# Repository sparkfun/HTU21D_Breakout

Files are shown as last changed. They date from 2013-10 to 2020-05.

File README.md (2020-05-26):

**NOTE:** *This product has been retired from our catalog. If you are looking for more up-to-date info, please check out some of these resources to see how other users are still hacking and improving on this product.*
* *[SparkFun Forum](https://forum.sparkfun.com/)*
* *[Comments Here on GitHub](https://github.com/sparkfun/HTU21D_Breakout/issues)*

*We recommend looking at the [Si7021](https://www.sparkfun.com/products/13763), which is a drop-in replacement for the HTU21D. It uses the same address and methods to read the sensor.*

SparkFun Humidity and Temperature Sensor Breakout - HTU21D
===========================================================

SparkFun Humidity and Temperature Sensor Breakout - HTU21D  

[*SparkFun Humidity and Temperature Sensor Breakout - HTU21D (SEN-12064)*](https://www.sparkfun.com/products/12064)

This is a breadboard friendly breakout board for the Measurement Specialties high-precision, low-power digital humidity sensor.

Repository Contents
-------------------
* **/Firmware** - Example code 
* **/Hardware** - Eagle design files (.brd, .sch)
* **/Libraries** - Libraries for use with the <PRODUCT NAME>
* **/Production** - Production panel files (.brd)

Documentation
--------------
* **[Library](https://github.com/sparkfun/SparkFun_HTU21D_Breakout_Arduino_Library)** - Arduino library for the HTU21D.
* **[Hookup Guide](https://learn.sparkfun.com/tutorials/htu21d-humidity-sensor-hookup-guide)** - Basic hookup guide for the HTU21D.
* **[SparkFun Fritzing repo](https://github.com/sparkfun/Fritzing_Parts)** - Fritzing diagrams for SparkFun products.
* **[SparkFun 3D Model repo](https://github.com/sparkfun/3D_Models)** - 3D models of SparkFun products. 

License Information
-------------------
This product is _**open source**_! 

The **hardware** is released under [Creative Commons ShareAlike 4.0 International](https://creativecommons.org/licenses/by-sa/4.0/).

The **code** is beerware; if you see me (or any other SparkFun employee) at the local, and you've found our code helpful, please buy us a round!

Please use, reuse, and modify these files as you see fit. Please maintain attribution to SparkFun Electronics and release anything derivative under the same license.

Distributed as-is; no warranty is given.

- Your friends at SparkFun.

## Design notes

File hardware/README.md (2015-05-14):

SparkFun <PRODUCT NAME> Design Files
=====================================

The .sch and .brd files hare are Eagle CAD schematic and PCB design files from SparkFun Electronics.
A freeware version of Eagle can be found [here](http://www.cadsoftusa.com/download-eagle/freeware/). 

License
---------
This product is open source! 
The hardware is released under [Creative Commons ShareAlike 4.0 International](https://creativecommons.org/licenses/by-sa/4.0/).

Please use, reuse, and modify these files as you see fit. Please maintain attribution to SparkFun Electronics and release anything derivative under the same license.

Distributed as-is; no warranty is given.

- Your friends at SparkFun.

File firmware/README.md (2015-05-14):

SparkFun HTU21D Firmware
===================================

* **HTU21D_SimpleSketch** - Arduino simple sketch example. See video [here](https://youtu.be/HfNsybUKU6U). 
* **SparkFun_HTU21D_Example** - Arduino example sketch for getting started. No library required.

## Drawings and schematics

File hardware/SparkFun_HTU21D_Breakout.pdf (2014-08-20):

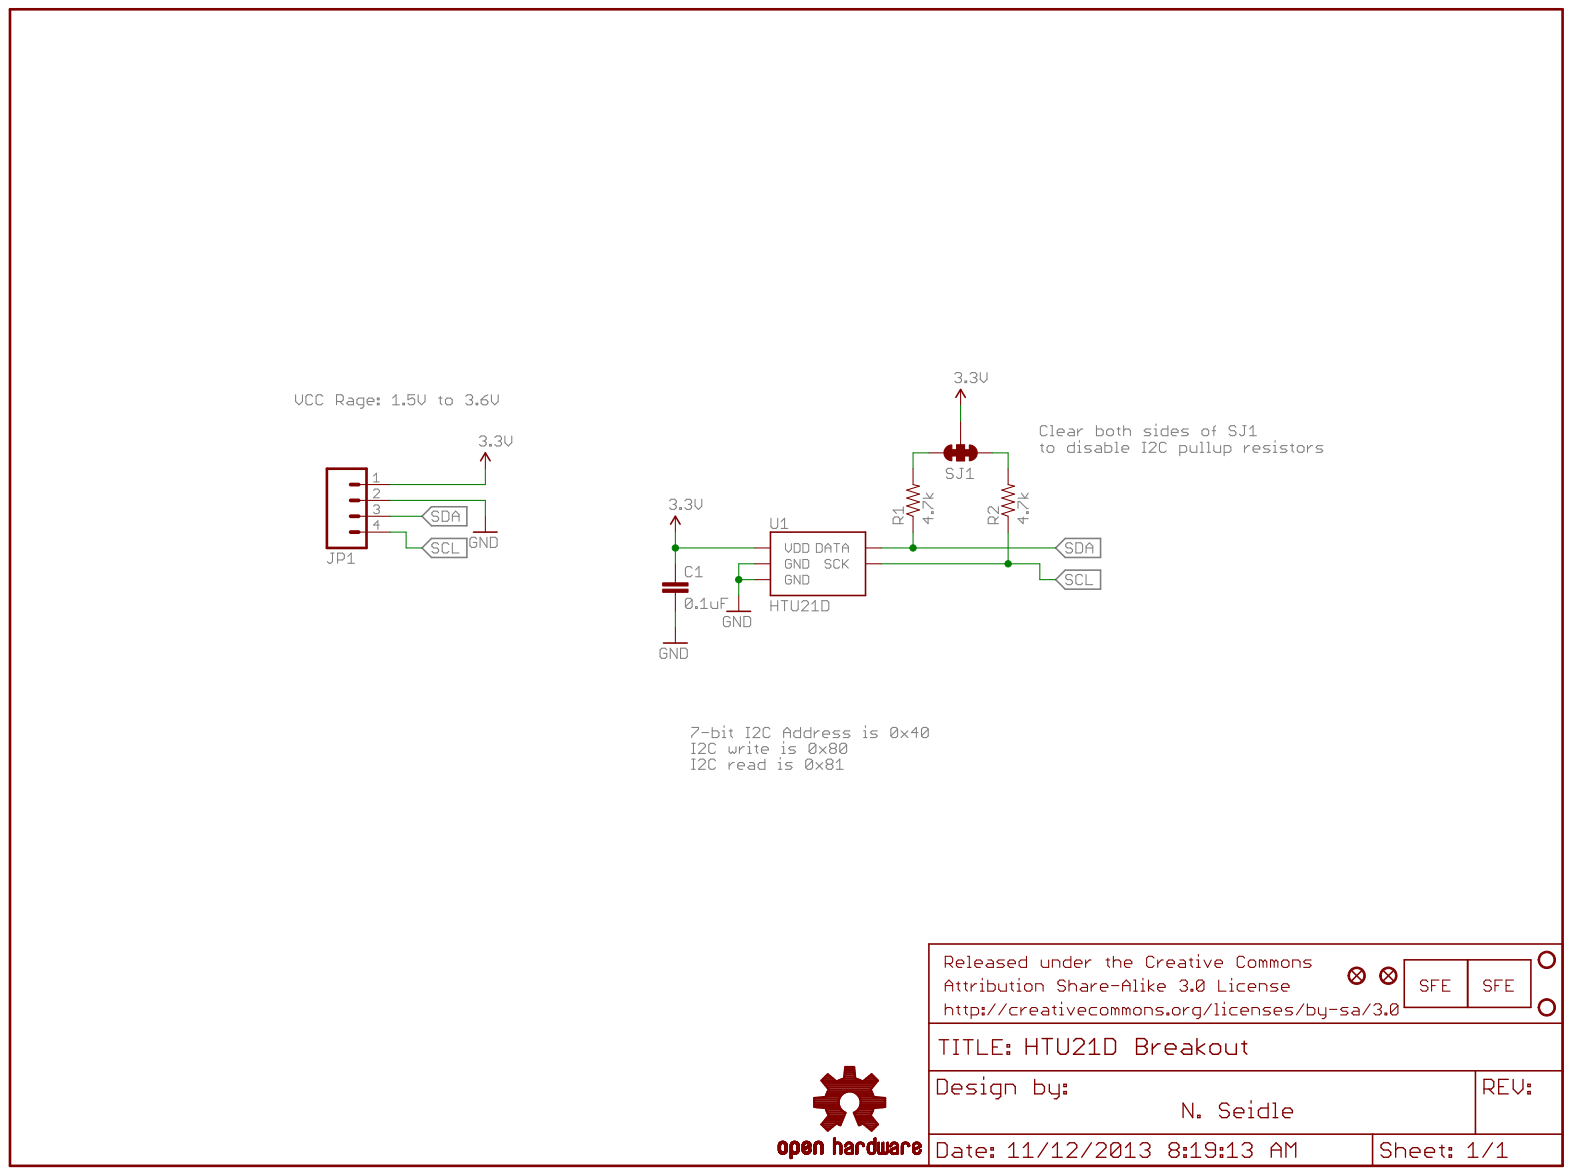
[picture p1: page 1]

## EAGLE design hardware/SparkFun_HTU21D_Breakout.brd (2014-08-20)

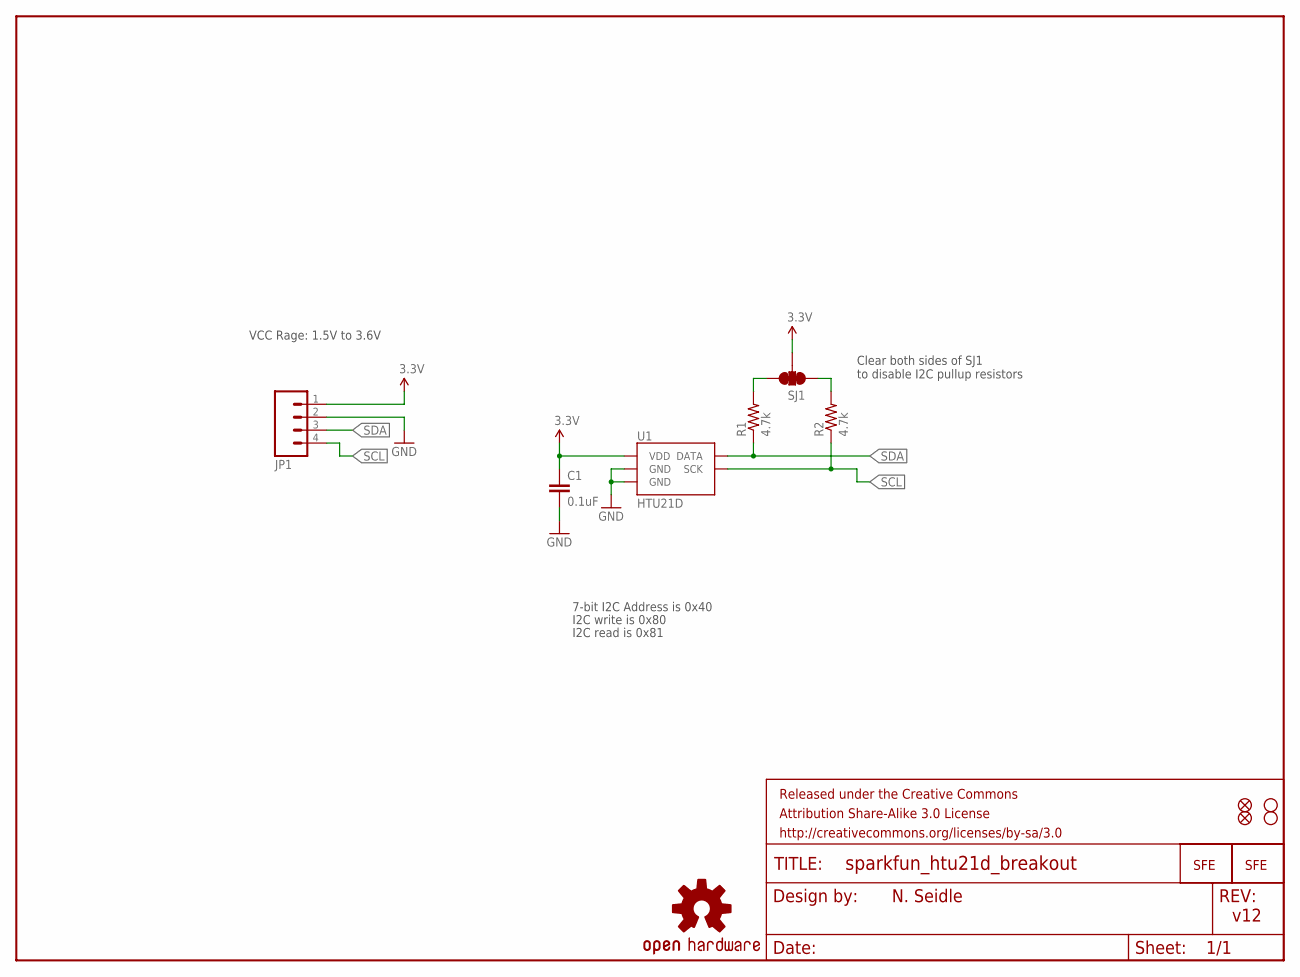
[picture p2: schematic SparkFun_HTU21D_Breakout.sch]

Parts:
C1: 0.1uF; 0603-CAP
FRAME2: FRAME-LETTER; CREATIVE_COMMONS
JP1: M04PTH; 1X04
JP2: LOGO-SFENW2; SFE-NEW-WEB
JP3, JP4: FIDUCIALUFIDUCIAL; MICRO-FIDUCIAL
LOGO1: LOGO-SFESK; SFE-LOGO-FLAME
LOGO2: OSHW-LOGOS; OSHW-LOGO-S
R1, R2: 4.7k; 0603-RES
SJ1: SOLDERJUMPER_2WAYPASTE1&2&3; SJ_3_PASTE1&2&3
STANDOFF1, STANDOFF2: STAND-OFF
U1: HTU21D

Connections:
3.3V: C1.1, JP1.1, SJ1.2, U1.VDD
GND: C1.2, JP1.2, U1.7 (GND), U1.GND
unnamed: R1.2, SJ1.3
unnamed: R2.2, SJ1.1
SCL: JP1.4, R2.1, U1.SCK
SDA: JP1.3, R1.1, U1.DATA

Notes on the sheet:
N. Seidle
Clear both sides of SJ1 to disable I2C pullup resistors
VCC Rage: 1.5V to 3.6V
7-bit I2C Address is 0x40
I2C write is 0x80
I2C read is 0x81
v12

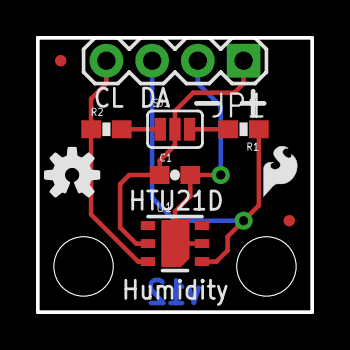
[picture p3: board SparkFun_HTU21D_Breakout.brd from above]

Board: 2 copper layers, 15.2 x 15.2 mm, 14 parts (1 on the bottom side), 6 nets.

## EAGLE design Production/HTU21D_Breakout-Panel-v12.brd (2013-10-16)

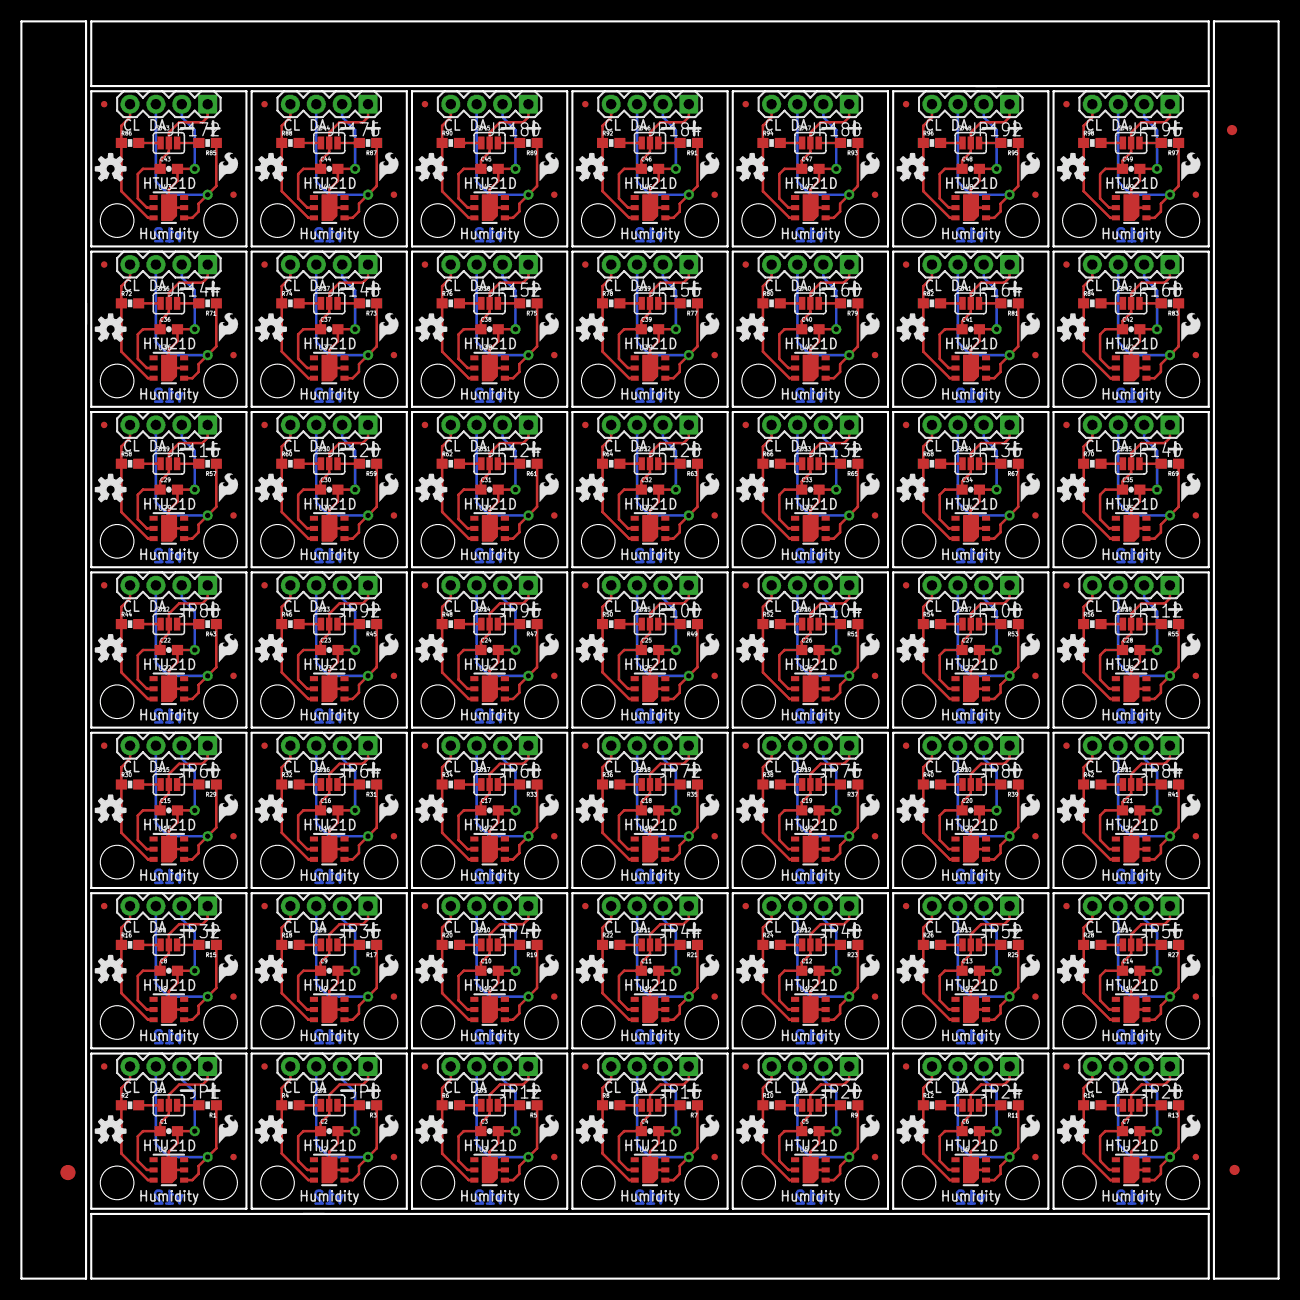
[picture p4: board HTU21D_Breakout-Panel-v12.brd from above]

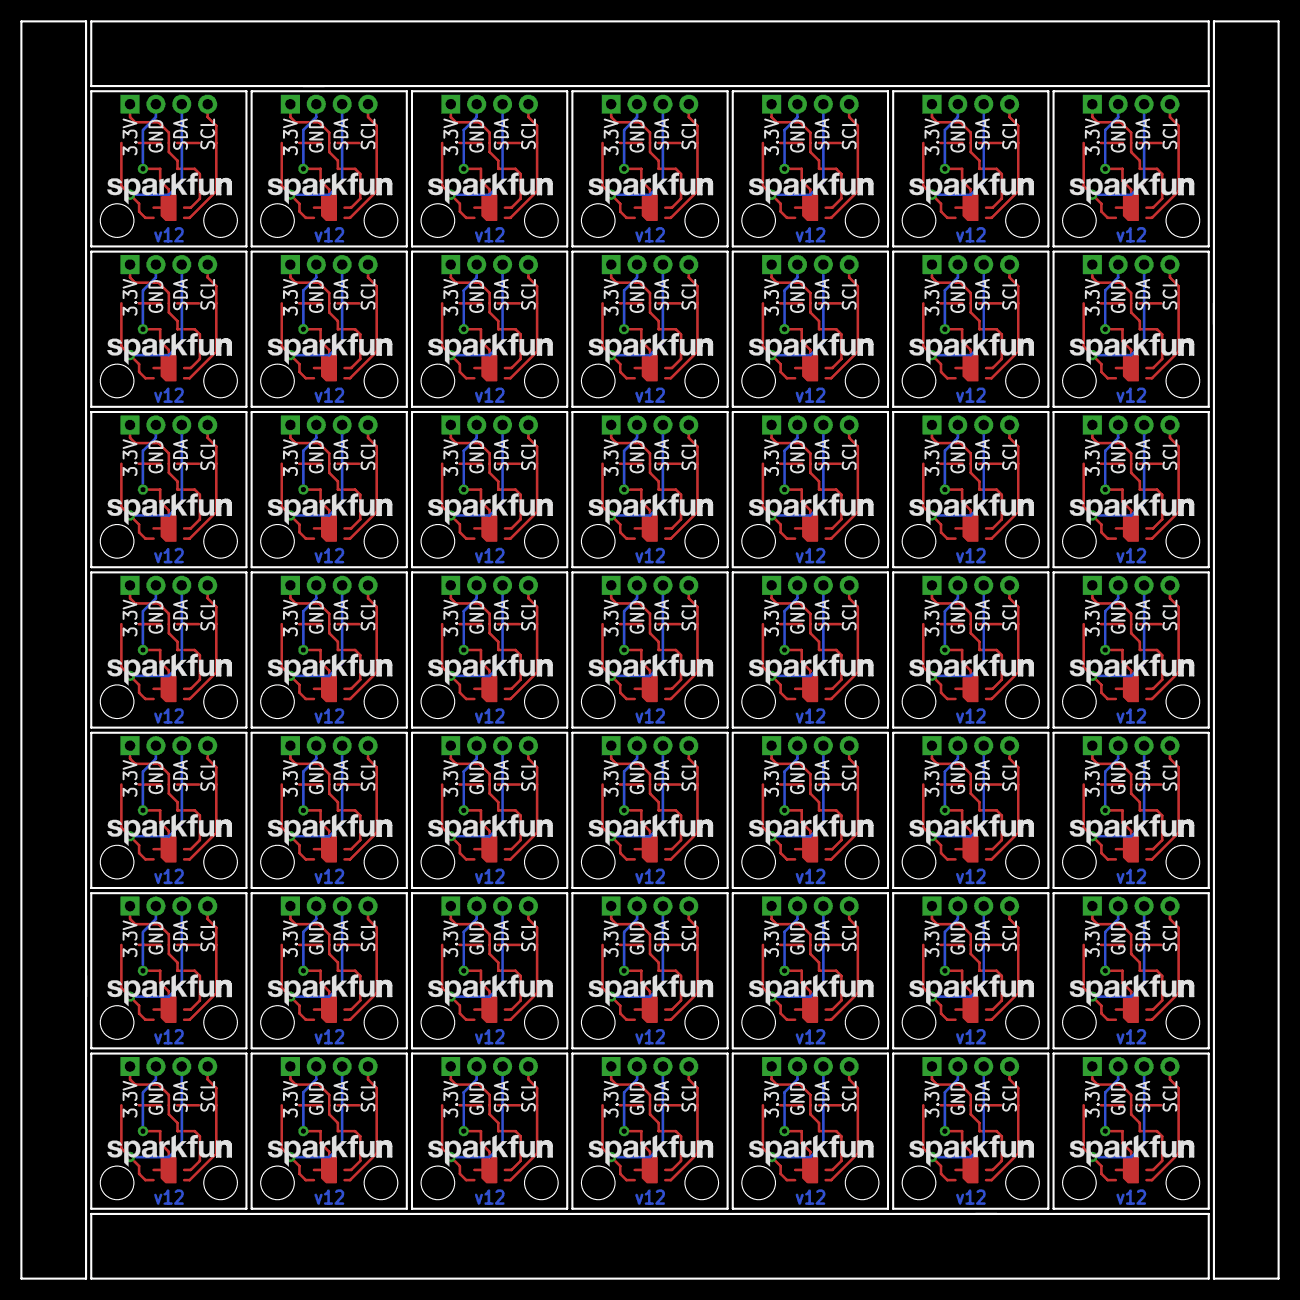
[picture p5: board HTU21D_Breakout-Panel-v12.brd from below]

Board: 2 copper layers, 123.4 x 123.4 mm, 640 parts (49 on the bottom side), 294 nets.

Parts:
C1, C2, C3, C4, C5, C6, C7, C8, C9, C10, C11, C12, C13, C14, C15, C16, C17, C18, C19, C20, C21, C22, C23, C24, C25, C26, C27, C28, C29, C30, C31, C32, C33, C34, C35, C36, C37, C38, C39, C40, C41, C42, C43, C44, C45, C46, C47, C48, C49: 0.1uF; 0603-CAP
E$1: FIDUCIAL-1.5X3
E$4, E$5: FIDUCIAL-1X2
JP1, JP8, JP12, JP16, JP20, JP24, JP28, JP32, JP36, JP40, JP44, JP48, JP52, JP56, JP60, JP64, JP68, JP72, JP76, JP80, JP84, JP88, JP92, JP96, JP100, JP104, JP108, JP112, JP116, JP120, JP124, JP128, JP132, JP136, JP140, JP144, JP148, JP152, JP156, JP160, JP164, JP168, JP172, JP176, JP180, JP184, JP188, JP192, JP196: 1X04
JP2, JP5, JP9, JP13, JP17, JP21, JP25, JP29, JP33, JP37, JP41, JP45, JP49, JP53, JP57, JP61, JP65, JP69, JP73, JP77, JP81, JP85, JP89, JP93, JP97, JP101, JP105, JP109, JP113, JP117, JP121, JP125, JP129, JP133, JP137, JP141, JP145, JP149, JP153, JP157, JP161, JP165, JP169, JP173, JP177, JP181, JP185, JP189, JP193: LOGO-SFENW2; SFE-NEW-WEB
JP3, JP4, JP6, JP7, JP10, JP11, JP14, JP15, JP18, JP19, JP22, JP23, JP26, JP27, JP30, JP31, JP34, JP35, JP38, JP39, JP42, JP43, JP46, JP47, JP50, JP51, JP54, JP55, JP58, JP59, JP62, JP63, JP66, JP67, JP70, JP71, JP74, JP75, JP78, JP79, JP82, JP83, JP86, JP87, JP90, JP91, JP94, JP95, JP98, JP99, JP102, JP103, JP106, JP107, JP110, JP111, JP114, JP115, JP118, JP119, JP122, JP123, JP126, JP127, JP130, JP131, JP134, JP135, JP138, JP139, JP142, JP143, JP146, JP147, JP150, JP151, JP154, JP155, JP158, JP159, JP162, JP163, JP166, JP167, JP170, JP171, JP174, JP175, JP178, JP179, JP182, JP183, JP186, JP187, JP190, JP191, JP194, JP195: FIDUCIALUFIDUCIAL; MICRO-FIDUCIAL
LOGO1, LOGO3, LOGO5, LOGO7, LOGO9, LOGO11, LOGO13, LOGO15, LOGO17, LOGO19, LOGO21, LOGO23, LOGO25, LOGO27, LOGO29, LOGO31, LOGO33, LOGO35, LOGO37, LOGO39, LOGO41, LOGO43, LOGO45, LOGO47, LOGO49, LOGO51, LOGO53, LOGO55, LOGO57, LOGO59, LOGO61, LOGO63, LOGO65, LOGO67, LOGO69, LOGO71, LOGO73, LOGO75, LOGO77, LOGO79, LOGO81, LOGO83, LOGO85, LOGO87, LOGO89, LOGO91, LOGO93, LOGO95, LOGO97: LOGO-SFESK; SFE-LOGO-FLAME
LOGO2, LOGO4, LOGO6, LOGO8, LOGO10, LOGO12, LOGO14, LOGO16, LOGO18, LOGO20, LOGO22, LOGO24, LOGO26, LOGO28, LOGO30, LOGO32, LOGO34, LOGO36, LOGO38, LOGO40, LOGO42, LOGO44, LOGO46, LOGO48, LOGO50, LOGO52, LOGO54, LOGO56, LOGO58, LOGO60, LOGO62, LOGO64, LOGO66, LOGO68, LOGO70, LOGO72, LOGO74, LOGO76, LOGO78, LOGO80, LOGO82, LOGO84, LOGO86, LOGO88, LOGO90, LOGO92, LOGO94, LOGO96, LOGO98: OSHW-LOGOS; OSHW-LOGO-S
R1, R2, R3, R4, R5, R6, R7, R8, R9, R10, R11, R12, R13, R14, R15, R16, R17, R18, R19, R20, R21, R22, R23, R24, R25, R26, R27, R28, R29, R30, R31, R32, R33, R34, R35, R36, R37, R38, R39, R40, R41, R42, R43, R44, R45, R46, R47, R48, R49, R50, R51, R52, R53, R54, R55, R56, R57, R58, R59, R60, R61, R62, R63, R64, R65, R66, R67, R68, R69, R70, R71, R72, R73, R74, R75, R76, R77, R78, R79, R80, R81, R82, R83, R84, R85, R86, R87, R88, R89, R90, R91, R92, R93, R94, R95, R96, R97, R98: 4.7k; 0603-RES
SJ1, SJ2, SJ3, SJ4, SJ5, SJ6, SJ7, SJ8, SJ9, SJ10, SJ11, SJ12, SJ13, SJ14, SJ15, SJ16, SJ17, SJ18, SJ19, SJ20, SJ21, SJ22, SJ23, SJ24, SJ25, SJ26, SJ27, SJ28, SJ29, SJ30, SJ31, SJ32, SJ33, SJ34, SJ35, SJ36, SJ37, SJ38, SJ39, SJ40, SJ41, SJ42, SJ43, SJ44, SJ45, SJ46, SJ47, SJ48, SJ49: SJ_3_PASTE1&2&3
STANDOFF1, STANDOFF2, STANDOFF3, STANDOFF4, STANDOFF5, STANDOFF6, STANDOFF7, STANDOFF8, STANDOFF9, STANDOFF10, STANDOFF11, STANDOFF12, STANDOFF13, STANDOFF14, STANDOFF15, STANDOFF16, STANDOFF17, STANDOFF18, STANDOFF19, STANDOFF20, STANDOFF21, STANDOFF22, STANDOFF23, STANDOFF24, STANDOFF25, STANDOFF26, STANDOFF27, STANDOFF28, STANDOFF29, STANDOFF30, STANDOFF31, STANDOFF32, STANDOFF33, STANDOFF34, STANDOFF35, STANDOFF36, STANDOFF37, STANDOFF38, STANDOFF39, STANDOFF40, STANDOFF41, STANDOFF42, STANDOFF43, STANDOFF44, STANDOFF45, STANDOFF46, STANDOFF47, STANDOFF48, STANDOFF49, STANDOFF50, STANDOFF51, STANDOFF52, STANDOFF53, STANDOFF54, STANDOFF55, STANDOFF56, STANDOFF57, STANDOFF58, STANDOFF59, STANDOFF60, STANDOFF61, STANDOFF62, STANDOFF63, STANDOFF64, STANDOFF65, STANDOFF66, STANDOFF67, STANDOFF68, STANDOFF69, STANDOFF70, STANDOFF71, STANDOFF72, STANDOFF73, STANDOFF74, STANDOFF75, STANDOFF76, STANDOFF77, STANDOFF78, STANDOFF79, STANDOFF80, STANDOFF81, STANDOFF82, STANDOFF83, STANDOFF84, STANDOFF85, STANDOFF86, STANDOFF87, STANDOFF88, STANDOFF89, STANDOFF90, STANDOFF91, STANDOFF92, STANDOFF93, STANDOFF94, STANDOFF95, STANDOFF96, STANDOFF97, STANDOFF98: STAND-OFF
U1, U2, U3, U4, U5, U6, U7, U8, U9, U10, U11, U12, U13, U14, U15, U16, U17, U18, U19, U20, U21, U22, U23, U24, U25, U26, U27, U28, U29, U30, U31, U32, U33, U34, U35, U36, U37, U38, U39, U40, U41, U42, U43, U44, U45, U46, U47, U48, U49: HTU21D

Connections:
3.3V: C1.1, JP1.1, SJ1.2, U1.VDD
3.3V1: C2.1, JP8.1, SJ2.2, U2.VDD
3.3V2: C3.1, JP12.1, SJ3.2, U3.VDD
3.3V3: C4.1, JP16.1, SJ4.2, U4.VDD
3.3V4: C5.1, JP20.1, SJ5.2, U5.VDD
3.3V5: C6.1, JP24.1, SJ6.2, U6.VDD
3.3V6: C7.1, JP28.1, SJ7.2, U7.VDD
3.3V7: C8.1, JP32.1, SJ8.2, U8.VDD
3.3V8: C9.1, JP36.1, SJ9.2, U9.VDD
3.3V9: C10.1, JP40.1, SJ10.2, U10.VDD
3.3V10: C11.1, JP44.1, SJ11.2, U11.VDD
3.3V11: C12.1, JP48.1, SJ12.2, U12.VDD
3.3V12: C13.1, JP52.1, SJ13.2, U13.VDD
3.3V13: C14.1, JP56.1, SJ14.2, U14.VDD
3.3V14: C15.1, JP60.1, SJ15.2, U15.VDD
3.3V15: C16.1, JP64.1, SJ16.2, U16.VDD
3.3V16: C17.1, JP68.1, SJ17.2, U17.VDD
3.3V17: C18.1, JP72.1, SJ18.2, U18.VDD
3.3V18: C19.1, JP76.1, SJ19.2, U19.VDD
3.3V19: C20.1, JP80.1, SJ20.2, U20.VDD
3.3V20: C21.1, JP84.1, SJ21.2, U21.VDD
3.3V21: C22.1, JP88.1, SJ22.2, U22.VDD
3.3V22: C23.1, JP92.1, SJ23.2, U23.VDD
3.3V23: C24.1, JP96.1, SJ24.2, U24.VDD
3.3V24: C25.1, JP100.1, SJ25.2, U25.VDD
3.3V25: C26.1, JP104.1, SJ26.2, U26.VDD
3.3V26: C27.1, JP108.1, SJ27.2, U27.VDD
3.3V27: C28.1, JP112.1, SJ28.2, U28.VDD
3.3V28: C29.1, JP116.1, SJ29.2, U29.VDD
3.3V29: C30.1, JP120.1, SJ30.2, U30.VDD
3.3V30: C31.1, JP124.1, SJ31.2, U31.VDD
3.3V31: C32.1, JP128.1, SJ32.2, U32.VDD
3.3V32: C33.1, JP132.1, SJ33.2, U33.VDD
3.3V33: C34.1, JP136.1, SJ34.2, U34.VDD
3.3V34: C35.1, JP140.1, SJ35.2, U35.VDD
3.3V35: C36.1, JP144.1, SJ36.2, U36.VDD
3.3V36: C37.1, JP148.1, SJ37.2, U37.VDD
3.3V37: C38.1, JP152.1, SJ38.2, U38.VDD
3.3V38: C39.1, JP156.1, SJ39.2, U39.VDD
3.3V39: C40.1, JP160.1, SJ40.2, U40.VDD
3.3V40: C41.1, JP164.1, SJ41.2, U41.VDD
3.3V41: C42.1, JP168.1, SJ42.2, U42.VDD
3.3V42: C43.1, JP172.1, SJ43.2, U43.VDD
3.3V43: C44.1, JP176.1, SJ44.2, U44.VDD
3.3V44: C45.1, JP180.1, SJ45.2, U45.VDD
3.3V45: C46.1, JP184.1, SJ46.2, U46.VDD
3.3V46: C47.1, JP188.1, SJ47.2, U47.VDD
3.3V47: C48.1, JP192.1, SJ48.2, U48.VDD
3.3V48: C49.1, JP196.1, SJ49.2, U49.VDD
GND: C1.2, JP1.2, U1.7, U1.GND
GND1: C2.2, JP8.2, U2.7, U2.GND
GND2: C3.2, JP12.2, U3.7, U3.GND
GND3: C4.2, JP16.2, U4.7, U4.GND
GND4: C5.2, JP20.2, U5.7, U5.GND
GND5: C6.2, JP24.2, U6.7, U6.GND
GND6: C7.2, JP28.2, U7.7, U7.GND
GND7: C8.2, JP32.2, U8.7, U8.GND
GND8: C9.2, JP36.2, U9.7, U9.GND
GND9: C10.2, JP40.2, U10.7, U10.GND
GND10: C11.2, JP44.2, U11.7, U11.GND
GND11: C12.2, JP48.2, U12.7, U12.GND
GND12: C13.2, JP52.2, U13.7, U13.GND
GND13: C14.2, JP56.2, U14.7, U14.GND
GND14: C15.2, JP60.2, U15.7, U15.GND
GND15: C16.2, JP64.2, U16.7, U16.GND
GND16: C17.2, JP68.2, U17.7, U17.GND
GND17: C18.2, JP72.2, U18.7, U18.GND
GND18: C19.2, JP76.2, U19.7, U19.GND
GND19: C20.2, JP80.2, U20.7, U20.GND
GND20: C21.2, JP84.2, U21.7, U21.GND
GND21: C22.2, JP88.2, U22.7, U22.GND
GND22: C23.2, JP92.2, U23.7, U23.GND
GND23: C24.2, JP96.2, U24.7, U24.GND
GND24: C25.2, JP100.2, U25.7, U25.GND
GND25: C26.2, JP104.2, U26.7, U26.GND
GND26: C27.2, JP108.2, U27.7, U27.GND
GND27: C28.2, JP112.2, U28.7, U28.GND
GND28: C29.2, JP116.2, U29.7, U29.GND
GND29: C30.2, JP120.2, U30.7, U30.GND
GND30: C31.2, JP124.2, U31.7, U31.GND
GND31: C32.2, JP128.2, U32.7, U32.GND
GND32: C33.2, JP132.2, U33.7, U33.GND
GND33: C34.2, JP136.2, U34.7, U34.GND
GND34: C35.2, JP140.2, U35.7, U35.GND
GND35: C36.2, JP144.2, U36.7, U36.GND
GND36: C37.2, JP148.2, U37.7, U37.GND
GND37: C38.2, JP152.2, U38.7, U38.GND
GND38: C39.2, JP156.2, U39.7, U39.GND
GND39: C40.2, JP160.2, U40.7, U40.GND
GND40: C41.2, JP164.2, U41.7, U41.GND
GND41: C42.2, JP168.2, U42.7, U42.GND
GND42: C43.2, JP172.2, U43.7, U43.GND
GND43: C44.2, JP176.2, U44.7, U44.GND
GND44: C45.2, JP180.2, U45.7, U45.GND
GND45: C46.2, JP184.2, U46.7, U46.GND
GND46: C47.2, JP188.2, U47.7, U47.GND
GND47: C48.2, JP192.2, U48.7, U48.GND
GND48: C49.2, JP196.2, U49.7, U49.GND
unnamed: R1.2, SJ1.3
unnamed: R2.2, SJ1.1
unnamed: R3.2, SJ2.3
unnamed: R4.2, SJ2.1
unnamed: R5.2, SJ3.3
unnamed: R6.2, SJ3.1
unnamed: R7.2, SJ4.3
unnamed: R8.2, SJ4.1
unnamed: R9.2, SJ5.3
unnamed: R10.2, SJ5.1
unnamed: R11.2, SJ6.3
unnamed: R12.2, SJ6.1
unnamed: R13.2, SJ7.3
unnamed: R14.2, SJ7.1
unnamed: R15.2, SJ8.3
unnamed: R16.2, SJ8.1
unnamed: R17.2, SJ9.3
unnamed: R18.2, SJ9.1
unnamed: R19.2, SJ10.3
unnamed: R20.2, SJ10.1
unnamed: R21.2, SJ11.3
unnamed: R22.2, SJ11.1
unnamed: R23.2, SJ12.3
unnamed: R24.2, SJ12.1
unnamed: R25.2, SJ13.3
unnamed: R26.2, SJ13.1
unnamed: R27.2, SJ14.3
unnamed: R28.2, SJ14.1
unnamed: R29.2, SJ15.3
unnamed: R30.2, SJ15.1
unnamed: R31.2, SJ16.3
unnamed: R32.2, SJ16.1
unnamed: R33.2, SJ17.3
unnamed: R34.2, SJ17.1
unnamed: R35.2, SJ18.3
unnamed: R36.2, SJ18.1
unnamed: R37.2, SJ19.3
unnamed: R38.2, SJ19.1
unnamed: R39.2, SJ20.3
unnamed: R40.2, SJ20.1
unnamed: R41.2, SJ21.3
unnamed: R42.2, SJ21.1
unnamed: R43.2, SJ22.3
unnamed: R44.2, SJ22.1
unnamed: R45.2, SJ23.3
unnamed: R46.2, SJ23.1
unnamed: R47.2, SJ24.3
unnamed: R48.2, SJ24.1
unnamed: R49.2, SJ25.3
unnamed: R50.2, SJ25.1
unnamed: R51.2, SJ26.3
unnamed: R52.2, SJ26.1
unnamed: R53.2, SJ27.3
unnamed: R54.2, SJ27.1
unnamed: R55.2, SJ28.3
unnamed: R56.2, SJ28.1
unnamed: R57.2, SJ29.3
unnamed: R58.2, SJ29.1
unnamed: R59.2, SJ30.3
unnamed: R60.2, SJ30.1
unnamed: R61.2, SJ31.3
unnamed: R62.2, SJ31.1
unnamed: R63.2, SJ32.3
unnamed: R64.2, SJ32.1
unnamed: R65.2, SJ33.3
unnamed: R66.2, SJ33.1
unnamed: R67.2, SJ34.3
unnamed: R68.2, SJ34.1
unnamed: R69.2, SJ35.3
unnamed: R70.2, SJ35.1
unnamed: R71.2, SJ36.3
unnamed: R72.2, SJ36.1
unnamed: R73.2, SJ37.3
unnamed: R74.2, SJ37.1
unnamed: R75.2, SJ38.3
unnamed: R76.2, SJ38.1
unnamed: R77.2, SJ39.3
unnamed: R78.2, SJ39.1
unnamed: R79.2, SJ40.3
unnamed: R80.2, SJ40.1
unnamed: R81.2, SJ41.3
unnamed: R82.2, SJ41.1
unnamed: R83.2, SJ42.3
unnamed: R84.2, SJ42.1
unnamed: R85.2, SJ43.3
unnamed: R86.2, SJ43.1
unnamed: R87.2, SJ44.3
unnamed: R88.2, SJ44.1
unnamed: R89.2, SJ45.3
unnamed: R90.2, SJ45.1
unnamed: R91.2, SJ46.3
unnamed: R92.2, SJ46.1
unnamed: R93.2, SJ47.3
unnamed: R94.2, SJ47.1
unnamed: R95.2, SJ48.3
unnamed: R96.2, SJ48.1
unnamed: R97.2, SJ49.3
unnamed: R98.2, SJ49.1
SCL: JP1.4, R2.1, U1.SCK
SCL1: JP8.4, R4.1, U2.SCK
SCL2: JP12.4, R6.1, U3.SCK
SCL3: JP16.4, R8.1, U4.SCK
SCL4: JP20.4, R10.1, U5.SCK
SCL5: JP24.4, R12.1, U6.SCK
SCL6: JP28.4, R14.1, U7.SCK
SCL7: JP32.4, R16.1, U8.SCK
SCL8: JP36.4, R18.1, U9.SCK
SCL9: JP40.4, R20.1, U10.SCK
SCL10: JP44.4, R22.1, U11.SCK
SCL11: JP48.4, R24.1, U12.SCK
SCL12: JP52.4, R26.1, U13.SCK
SCL13: JP56.4, R28.1, U14.SCK
SCL14: JP60.4, R30.1, U15.SCK
SCL15: JP64.4, R32.1, U16.SCK
SCL16: JP68.4, R34.1, U17.SCK
SCL17: JP72.4, R36.1, U18.SCK
SCL18: JP76.4, R38.1, U19.SCK
SCL19: JP80.4, R40.1, U20.SCK
SCL20: JP84.4, R42.1, U21.SCK
SCL21: JP88.4, R44.1, U22.SCK
SCL22: JP92.4, R46.1, U23.SCK
SCL23: JP96.4, R48.1, U24.SCK
SCL24: JP100.4, R50.1, U25.SCK
SCL25: JP104.4, R52.1, U26.SCK
SCL26: JP108.4, R54.1, U27.SCK
SCL27: JP112.4, R56.1, U28.SCK
SCL28: JP116.4, R58.1, U29.SCK
SCL29: JP120.4, R60.1, U30.SCK
SCL30: JP124.4, R62.1, U31.SCK
SCL31: JP128.4, R64.1, U32.SCK
SCL32: JP132.4, R66.1, U33.SCK
SCL33: JP136.4, R68.1, U34.SCK
SCL34: JP140.4, R70.1, U35.SCK
SCL35: JP144.4, R72.1, U36.SCK
SCL36: JP148.4, R74.1, U37.SCK
SCL37: JP152.4, R76.1, U38.SCK
SCL38: JP156.4, R78.1, U39.SCK
SCL39: JP160.4, R80.1, U40.SCK
SCL40: JP164.4, R82.1, U41.SCK
SCL41: JP168.4, R84.1, U42.SCK
SCL42: JP172.4, R86.1, U43.SCK
SCL43: JP176.4, R88.1, U44.SCK
SCL44: JP180.4, R90.1, U45.SCK
SCL45: JP184.4, R92.1, U46.SCK
SCL46: JP188.4, R94.1, U47.SCK
SCL47: JP192.4, R96.1, U48.SCK
SCL48: JP196.4, R98.1, U49.SCK
SDA: JP1.3, R1.1, U1.DATA
SDA1: JP8.3, R3.1, U2.DATA
SDA2: JP12.3, R5.1, U3.DATA
SDA3: JP16.3, R7.1, U4.DATA
SDA4: JP20.3, R9.1, U5.DATA
SDA5: JP24.3, R11.1, U6.DATA
SDA6: JP28.3, R13.1, U7.DATA
SDA7: JP32.3, R15.1, U8.DATA
SDA8: JP36.3, R17.1, U9.DATA
SDA9: JP40.3, R19.1, U10.DATA
SDA10: JP44.3, R21.1, U11.DATA
SDA11: JP48.3, R23.1, U12.DATA
SDA12: JP52.3, R25.1, U13.DATA
SDA13: JP56.3, R27.1, U14.DATA
SDA14: JP60.3, R29.1, U15.DATA
SDA15: JP64.3, R31.1, U16.DATA
SDA16: JP68.3, R33.1, U17.DATA
SDA17: JP72.3, R35.1, U18.DATA
SDA18: JP76.3, R37.1, U19.DATA
SDA19: JP80.3, R39.1, U20.DATA
SDA20: JP84.3, R41.1, U21.DATA
SDA21: JP88.3, R43.1, U22.DATA
SDA22: JP92.3, R45.1, U23.DATA
SDA23: JP96.3, R47.1, U24.DATA
SDA24: JP100.3, R49.1, U25.DATA
SDA25: JP104.3, R51.1, U26.DATA
SDA26: JP108.3, R53.1, U27.DATA
SDA27: JP112.3, R55.1, U28.DATA
SDA28: JP116.3, R57.1, U29.DATA
SDA29: JP120.3, R59.1, U30.DATA
SDA30: JP124.3, R61.1, U31.DATA
SDA31: JP128.3, R63.1, U32.DATA
SDA32: JP132.3, R65.1, U33.DATA
SDA33: JP136.3, R67.1, U34.DATA
SDA34: JP140.3, R69.1, U35.DATA
SDA35: JP144.3, R71.1, U36.DATA
SDA36: JP148.3, R73.1, U37.DATA
SDA37: JP152.3, R75.1, U38.DATA
SDA38: JP156.3, R77.1, U39.DATA
SDA39: JP160.3, R79.1, U40.DATA
SDA40: JP164.3, R81.1, U41.DATA
SDA41: JP168.3, R83.1, U42.DATA
SDA42: JP172.3, R85.1, U43.DATA
SDA43: JP176.3, R87.1, U44.DATA
SDA44: JP180.3, R89.1, U45.DATA
SDA45: JP184.3, R91.1, U46.DATA
SDA46: JP188.3, R93.1, U47.DATA
SDA47: JP192.3, R95.1, U48.DATA
SDA48: JP196.3, R97.1, U49.DATA

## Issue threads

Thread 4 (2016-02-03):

Negative RH Readout?

epillar, 2016-02-03:
So I want to thank you first off for making this code readily available. It's helped me a lot with getting my project up and running.

 The temperature seems to be fine, but when I approach ~ 60% RH the sensor starts to read like -67% RH. As the RH increases further, it reads less negative. So from 60 to near 70% RH it outputs -67 to -58%

Is there something wrong with the sensor or is there a way I can code around this.

nseidle, 2016-10-24:
Hi epillar,

I apologize for the very slow reply! I was not able to replicate your issue. We just updated the library with a handful of new features. Please post if you are still having issues.

Closed 2016-10-24.

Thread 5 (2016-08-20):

No need to wait for data after Wire.requestFrom()

Koepel, 2016-08-20:
In SparkFun_HTU21D_Example.ino, there is a while-loop with a delay after the Wire.requestFrom() call. That while-loop is not needed and that delay is not needed.

When the Wire.requestFrom() function returns, the I2C transaction has completely finished and the received data is in the receive buffer in the Wire library. The Wire.read() only reads data from that buffer.

To test if a I2C error or I2C collision did happen, only one test is needed for the number of received bytes. That can be the return value of Wire.requestFrom() or with Wire.available().

nseidle, 2016-10-24:
You are correct, a Wire.requestFrom() will return a value without blocking the rest of the code. However, if the sensor is internally calculating, requestFrom will return zeros. These while-loop with delay tricks may be necessary for some sensors while we wait for the sensor to complete its calcs. (I haven't yet dug into the MPL3115A2 to figure out if it is or is not one).

    //Hang out while measurement is taken. datasheet says 50ms, practice may call for more
    byte toRead;
    byte counter;
    for (counter = 0, toRead = 0 ; counter < MAX_COUNTER && toRead != 3 ; counter++)
    {
      delay(DELAY_INTERVAL);

      //Comes back in three bytes, data(MSB) / data(LSB) / Checksum
      toRead = _i2cPort->requestFrom(HTU21D_ADDRESS, 3);
    }

The current implementation works well. Please create a pull request if there's a more elegant solution.

nseidle, 2016-10-24:
This repo just has a sub-branch of the library. Please see https://github.com/sparkfun/SparkFun_HTU21D_Breakout_Arduino_Library for actual library work.

Koepel, 2016-10-25:
Sorry, I was confused with the repo's.
The new code is okay. I think the delay can be 1ms as well. That might generate about 20 trials on the I2C bus, but that's no problem.

nseidle, 2016-10-25:
Awesome! Thanks for trying to make things better - we welcome the help.

Closed 2016-10-24.

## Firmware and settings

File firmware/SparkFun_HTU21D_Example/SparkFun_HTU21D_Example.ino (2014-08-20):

/* 
 HTU21D Humidity Sensor Example Code
 By: Nathan Seidle
 SparkFun Electronics
 Date: September 15th, 2013
 License: This code is public domain but you buy me a beer if you use this and we meet someday (Beerware license).
 
 Get humidity and temperature from the HTU21D sensor.
 
 Hardware Connections (Breakoutboard to Arduino):
 -VCC = 3.3V
 -GND = GND
 -SDA = A4
 -SCL = A5
 
 Serial.print it out at 9600 baud to serial monitor.
 */

#include <Wire.h>

#define HTDU21D_ADDRESS 0x40  //Unshifted 7-bit I2C address for the sensor

#define TRIGGER_TEMP_MEASURE_HOLD  0xE3
#define TRIGGER_HUMD_MEASURE_HOLD  0xE5
#define TRIGGER_TEMP_MEASURE_NOHOLD  0xF3
#define TRIGGER_HUMD_MEASURE_NOHOLD  0xF5
#define WRITE_USER_REG  0xE6
#define READ_USER_REG  0xE7
#define SOFT_RESET  0xFE

byte sensorStatus;

void setup()
{
  Serial.begin(9600);
  Serial.println("HTU21D Example!");

  Wire.begin();
}

void loop()
{
  unsigned int rawHumidity = htdu21d_readHumidity();
  unsigned int rawTemperature = htdu21d_readTemp();

  float temperature = calc_temp(rawTemperature);
  float relativeHumidity = calc_humidity(rawHumidity); //Turn the humidity signal into actual humidity

  Serial.print("Temperature: ");
  Serial.print(temperature, 1); //Print float with one decimal
  Serial.print(" C");
  Serial.print(" Relative Humidity: ");
  Serial.print(relativeHumidity, 1);
  Serial.print(" %");
  Serial.println();
  delay(1000);
}

//Read the uncompensated temperature value
unsigned int htdu21d_readTemp()
{
  //Request the temperature
  Wire.beginTransmission(HTDU21D_ADDRESS);
  Wire.write(TRIGGER_TEMP_MEASURE_NOHOLD);
  Wire.endTransmission();

  //Wait for sensor to complete measurement
  delay(60); //44-50 ms max - we could also poll the sensor

  //Comes back in three bytes, data(MSB) / data(LSB) / CRC
  Wire.requestFrom(HTDU21D_ADDRESS, 3);

  //Wait for data to become available
  int counter = 0;
  while(Wire.available() < 3)
  {
    counter++;
    delay(1);
    if(counter > 100) return 998; //Error out
  }

  unsigned char msb, lsb, crc;
  msb = Wire.read();
  lsb = Wire.read();
  crc = Wire.read(); //We don't do anything with CRC for now

  unsigned int temperature = ((unsigned int)msb << 8) | lsb;
  temperature &= 0xFFFC; //Zero out the status bits but keep them in place

  return temperature;
}

//Read the humidity
unsigned int htdu21d_readHumidity()
{
  byte msb, lsb, checksum;

  //Request a humidity reading
  Wire.beginTransmission(HTDU21D_ADDRESS);
  Wire.write(TRIGGER_HUMD_MEASURE_NOHOLD); //Measure humidity with no bus holding
  Wire.endTransmission();

  //Hang out while measurement is taken. 50mS max, page 4 of datasheet.
  delay(55);

  //Read result
  Wire.requestFrom(HTDU21D_ADDRESS, 3);

  //Wait for data to become available
  int counter = 0;
  while(Wire.available() < 3)
  {
    counter++;
    delay(1);
    if(counter > 100) return 0; //Error out
  }

  msb = Wire.read();
  lsb = Wire.read();
  checksum = Wire.read();

  unsigned int rawHumidity = ((unsigned int) msb << 8) | (unsigned int) lsb;
  rawHumidity &= 0xFFFC; //Zero out the status bits but keep them in place

  return(rawHumidity);
}

//Given the raw temperature data, calculate the actual temperature
float calc_temp(int SigTemp)
{
  float tempSigTemp = SigTemp / (float)65536; //2^16 = 65536
  float realTemperature = -46.85 + (175.72 * tempSigTemp); //From page 14

  return(realTemperature);  
}

//Given the raw humidity data, calculate the actual relative humidity
float calc_humidity(int SigRH)
{
  float tempSigRH = SigRH / (float)65536; //2^16 = 65536
  float rh = -6 + (125 * tempSigRH); //From page 14

  return(rh);  
}

//Read the user register
byte read_user_register(void)
{
  byte userRegister;

  //Request the user register
  Wire.beginTransmission(HTDU21D_ADDRESS);
  Wire.write(READ_USER_REG); //Read the user register
  Wire.endTransmission();

  //Read result
  Wire.requestFrom(HTDU21D_ADDRESS, 1);

  userRegister = Wire.read();

  return(userRegister);  
}

//Write to the user register
//NOTE: We disable all bits except for measurement resolution
//Bit 7 & 0 = Measurement resolution
//Bit 6 = Status of battery
//Bit 5/4/3 = Reserved
//Bit 2 = Enable on-board heater
//Bit 1 = Disable OTP reload
void write_user_register(byte thing_to_write)
{
  byte userRegister = read_user_register(); //Go get the current register state
  userRegister &= 0b01111110; //Turn off the resolution bits
  thing_to_write &= 0b10000001; //Turn off all other bits but resolution bits
  userRegister |= thing_to_write; //Mask in the requested resolution bits

  //Request a write to user register
  Wire.beginTransmission(HTDU21D_ADDRESS);
  Wire.write(WRITE_USER_REG); //Write to the user register
  Wire.write(userRegister); //Write to the data
  Wire.endTransmission();
}

//Give this function the 2 byte message (measurement) and the check_value byte from the HTU21D
//If it returns 0, then the transmission was good
//If it returns something other than 0, then the communication was corrupted
//From: http://www.nongnu.org/avr-libc/user-manual/group__util__crc.html
//POLYNOMIAL = 0x0131 = x^8 + x^5 + x^4 + 1 : http://en.wikipedia.org/wiki/Computation_of_cyclic_redundancy_checks
#define SHIFTED_DIVISOR 0x988000 //This is the 0x0131 polynomial shifted to farthest left of three bytes

unsigned int check_crc(uint16_t message_from_sensor, uint8_t check_value_from_sensor)
{
  //Test cases from datasheet:
  //message = 0xDC, result is 0x79
  //message = 0x683A, result is 0x7C
  //message = 0x4E85, result is 0x6B

  uint32_t remainder = (uint32_t)message_from_sensor << 8; //Pad with 8 bits because we have to add in the result/check value
  remainder |= check_value_from_sensor; //Add on the check value

  uint32_t divsor = (uint32_t)SHIFTED_DIVISOR;

  for (int i = 0 ; i < 16 ; i++) //Operate on only 16 positions of max 24. The remaining 8 are our remainder and should be zero when we're done.
  {
    //Serial.print("remainder:  ");
    //Serial.println(remainder, BIN);
    //Serial.print("divsor:     ");
    //Serial.println(divsor, BIN);
    //Serial.println();

    if( remainder & (uint32_t)1<<(23 - i) ) //Check if there is a one in the left position
      remainder ^= divsor;

    divsor >>= 1; //Rotate the divsor max 16 times so that we have 8 bits left of a remainder
  }

  return remainder;
}

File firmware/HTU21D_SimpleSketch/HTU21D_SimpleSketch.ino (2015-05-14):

/* 
 HTU21D Simple Sketch demo
Dave@sparkfun 
 SparkFun Electronics
 License: This code is public domain but you buy me a beer if you use this and we meet someday (Beerware license).
 
 Get humidity and temperature from the HTU21D sensor.
 
 Hardware Connections (Breakoutboard to Arduino):
 -VCC = 3.3V
 -GND = GND
 -SDA = A4
 -SCL = A5
 
 Serial.print it out at 9600 baud to serial monitor.
 */

#include <Wire.h>
#include <SparkFunHTU21D.h>
#include <SoftwareSerial.h>

SoftwareSerial display(3, 2);

//Create an instance of the object
HTU21D myHumidity;

char humstring[10];
char tmpstring[10];

float humidity;
float temperature;

int ihum;
int itemp;

void setup()
{
  Wire.begin();        // Join i2c bus
  Serial.begin(9600);  // Start serial for output

  myHumidity.begin(); // Get sensor online

  display.begin(9600);
  Serial.begin(9600);
  delay(500);

  display.write(254); // move cursor to beginning of first line
  display.write(128);

  display.write("                "); // clear display
  display.write("                ");
}

void loop()
{
  humidity = myHumidity.readHumidity();
  ihum = humidity;
  sprintf(humstring, "%2d", ihum);

  Serial.print("Humidity: ");
  Serial.println(humstring);
  Serial.print("%");

  display.write("Humidity: ");
  display.write(humstring);

  display.write(254); // move cursor to beginning of first line
  display.write(128);

  delay(250);
}

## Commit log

2013-09-16 Initial commit. Example code doesn't yet work.
    Board layout is solid, but example code is still in the works.
    [HTU21D Breakout.brd, HTU21D Breakout.sch]
2013-09-16 More changes to the code and repo.
    [HTU21D Breakout-NoBigSilk.brd, HTU21D Breakout-NoBigSilk.sch]
2013-09-17 Re-routing post review with engineering recommendations.
    Moved to 0603 footprints. Removed ground planes to align with datasheet
    thermal recommendations. Added OSHW logo. Updated frame to CC 3.0. Added
    revision code to bottom copper.
    [HTU21D Breakout-NoBigSilk.brd, HTU21D Breakout-NoBigSilk.sch, HTU21D Breakout.brd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]
2013-09-17 Added flags on data lines to schematic.
    [HTU21D Breakout.brd, HTU21D Breakout.sch]
2013-09-20 Corrected a reversed the footprint.
    Arg! I forgot to invert the footprint. Corrected.
    [HTU21D Breakout.brd, HTU21D Breakout.sch]
2013-09-20 Updated version number on layout to v11.
    [HTU21D Breakout.brd]
2013-10-12 Example code, layout, and library working.
    Added small 'humidity' text to board.
    [HTU21D Breakout.brd]
2013-10-14 Panel Created
    [HTU21D-Breakout-Panel-v11.brd]
2013-10-15 Corrected tcream on footprint on v12.
    Tcream was too small on center pad. Updated board with latest lib fixed
    it.
    [HTU21D Breakout.brd, HTU21D Breakout.sch]
2013-10-16 Recreated Panel
    [HTU21D Breakout-Panel-v12.brd]
2013-11-11 Adding fritzing part
    [HTU21D Breakout.brd, HTU21D Breakout.sch, HTU21D-Breakout-Panel-v11.brd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]
2013-11-11 Correcting directory structure
    [HTU21D Breakout.brd, HTU21D Breakout.sch, HTU21D-Breakout-Panel-v11.brd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]
2013-11-12 Added comments to example code.
    [Hookup.fzz]
2013-11-14 Updated readme. Cosmetic changes to schematic.
    [HTU21D Breakout.sch, Hookup.fzz]
2014-01-16 Updating example in library to use 330 inline resistors at 5V
2014-08-19 Cleared compiler warnings - begin() does not return a value -- changed the return type to "void" - explicitly cast initialization value to float - used binary constant from Arduino's binary.h, instea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
2015-05-14 Updating firmware files, fixing naming issues
    [SparkFun_HTU21D_Breakout.brd, SparkFun_HTU21D_Breakout.sch]
2015-05-14 Fixing readme links, production directory name, removing Fritzing diagrams to main Fritzing repo
    [HTU21D_Breakout-Panel-v12.brd, Hookup.fzz]
2015-05-14 Squashed 'Libraries/Arduino/' content from commit db0d027
    git-subtree-dir: Libraries/Arduino
    git-subtree-split: db0d027d4c8ff2eca0a532afa359a7c6fcbcc55f
2015-07-13 Squashed 'Libraries/Arduino/' changes from db0d027..2ff23bf
    2ff23bf Update library.properties
    git-subtree-split: 2ff23bff475d03202598204878445e841019ae69
    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
2015-08-04 Squashed 'Libraries/Arduino/' changes from 2ff23bf..fdacea6
    fdacea6 Fixing library name typo
    git-subtree-split: fdacea6cd009e2d1a5eddf22aaa42cfad06e464d
    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
2016-10-24 Squashed 'Libraries/Arduino/' changes from fdacea6..515623d
    515623d Update to genericized definition of I2C port
    b04a2a0 Read functions now return errors correctly
    f1379a0 Correcting RaNo99 issue 4. Changing variable names to fit Arduino style guide.
    93d8ead Fixing typo in IC define. Non-critical.
    0295c8c Updating lib ver #. Splitting baruch's code into a separate example.
    08e008e Merge pull request #3 from baruch/master
    0a1b740 Merge pull request #2 from RonBeck62/patch-1
    61a5dbf Read and write the user register
    470546f Optimize time to read data by multiple retries
    0d64eb2 Increase wait time
    aafdd91 Refactor common code to its own function
    1a6a9f9 Update SparkFunHTU21D.cpp
    git-subtree-dir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

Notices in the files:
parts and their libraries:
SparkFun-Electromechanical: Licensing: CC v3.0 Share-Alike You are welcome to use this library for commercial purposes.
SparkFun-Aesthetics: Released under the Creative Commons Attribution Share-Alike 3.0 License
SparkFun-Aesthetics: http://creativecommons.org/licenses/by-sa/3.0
